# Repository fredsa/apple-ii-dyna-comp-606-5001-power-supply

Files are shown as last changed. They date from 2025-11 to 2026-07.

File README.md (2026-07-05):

# Apple II 605-5703 (DynaComp 606-5001) Power Supply 110v

- KiCad schematic reverse-engineered by Fred Sauer in 2025, 2026.

- Part numbers and compontent layout updated to match power supply schematic
  published in _The Apple II Circuit Description_ (reprint of
  _Apple II Reference Manual 1981_), except for differences indicated by dotted
  outlines marked `diff`.

- Refer to [U.S. Patent 4,130,862](https://patents.google.com/patent/US4130862A)
  for an explanation of key design features of this power supply.

- KiCad and PDF schematic can be found in the `Dyna-Comp-606-5001-KiCad/`
  folder.

<hr>

<table>
  <caption>KiCad schematic</caption>
  <tr>
    <td>
      <a href="Dyna-Comp-606-5001-KiCad.svg">Dyna-Comp-606-5001-KiCad.svg</a><br>
      <a href="Dyna-Comp-606-5001-KiCad.pdf">Dyna-Comp-606-5001-KiCad.pdf</a><br>
    </td>
  </tr>
  <tr>
    <td></td>
  </tr>
</table>

<table>
  <caption>Main circuit board</caption>
  <tr>
    <td>Bottom side (flipped)</td>
    <td>Top side</td>
  </tr>
  <tr>
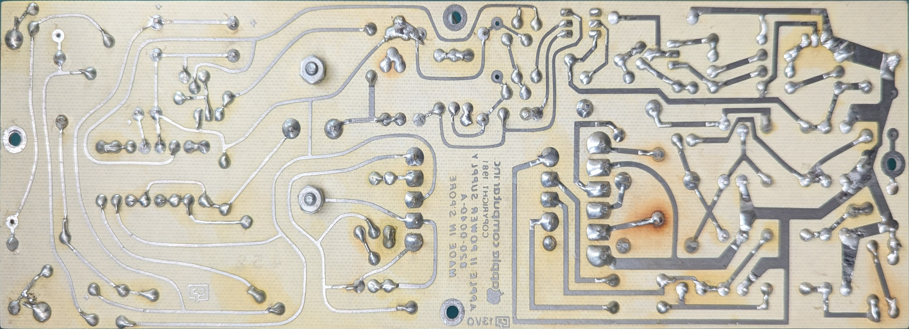
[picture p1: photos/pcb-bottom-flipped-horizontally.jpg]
    <td></td>
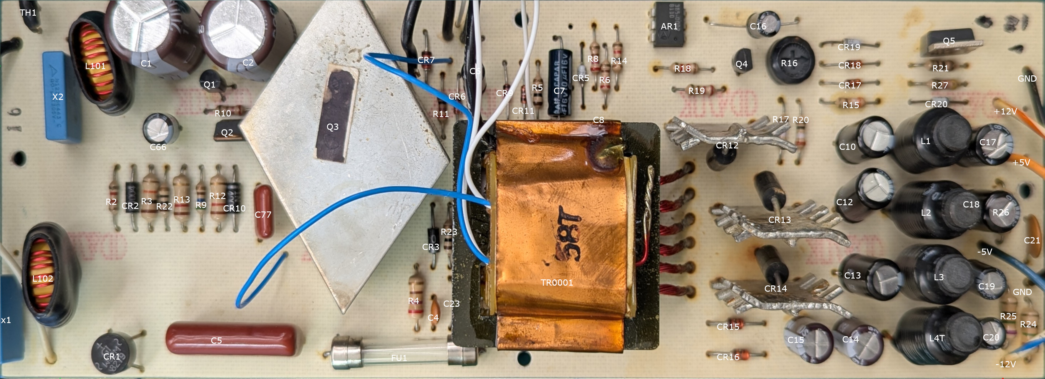
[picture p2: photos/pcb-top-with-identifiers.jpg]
    <td></td>
  </tr>
</table>

<table>
  <caption>Line filter</caption>
  <tr>
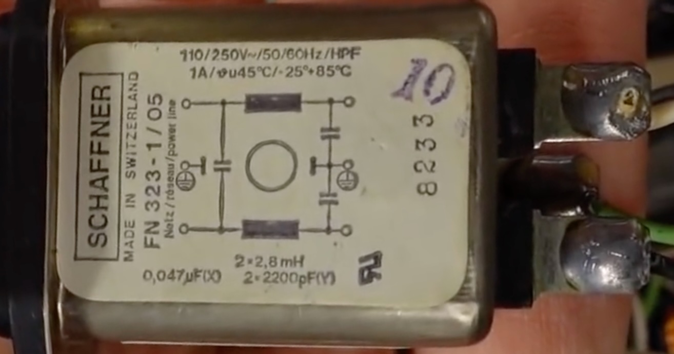
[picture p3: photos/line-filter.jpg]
    <td></td>
  </tr>
</table>

Model number `606-5001`

Specifications: `120 VAC` `60 Hz, 1 AMP`

Made in `DynaComp, Richardson, TX`:

<table>
  <caption>Line filter</caption>
  <tr>
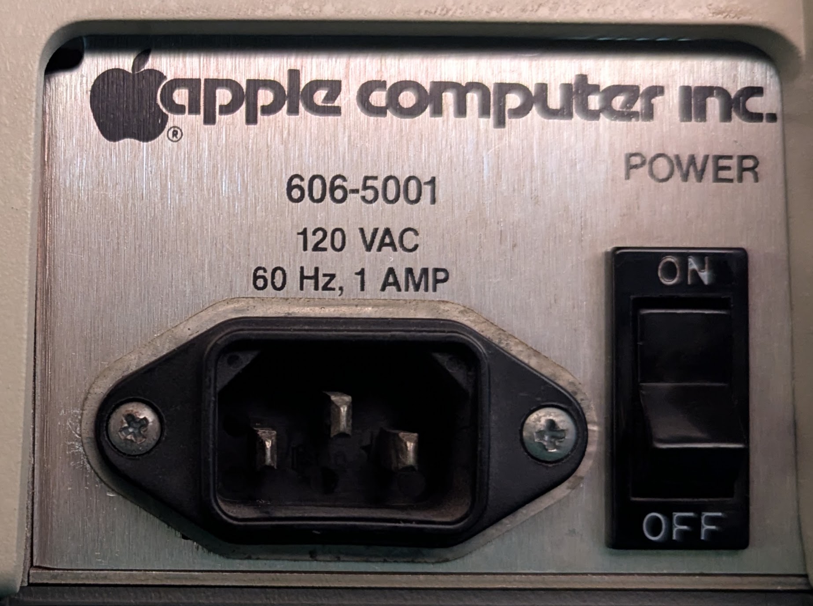
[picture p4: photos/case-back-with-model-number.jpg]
    <td></td>
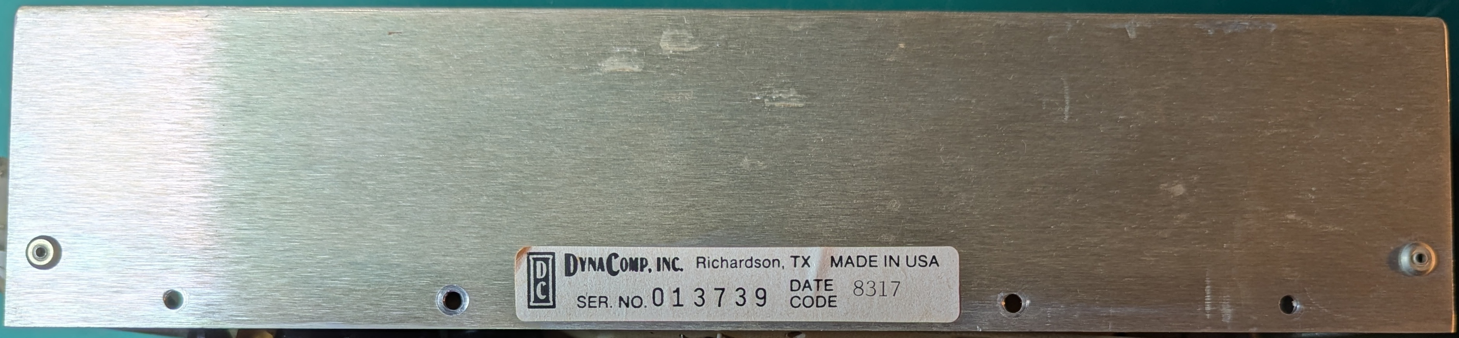
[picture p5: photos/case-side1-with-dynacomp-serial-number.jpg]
    <td></td>
  </tr>
</table>

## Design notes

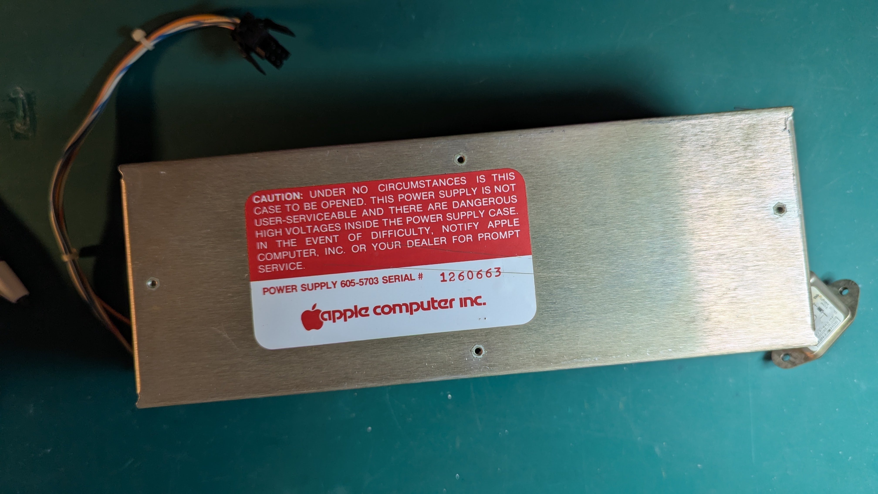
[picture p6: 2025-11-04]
photos/case-side2-with-apple-serial-number.jpg

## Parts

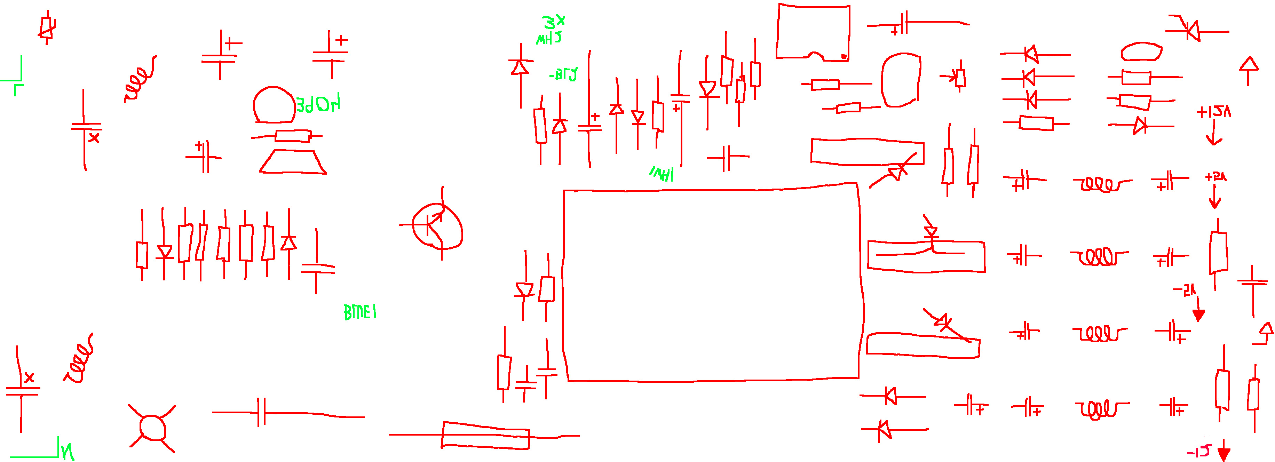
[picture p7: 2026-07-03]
photos/pcb-bottom-components-flipped-horizontally.jpg

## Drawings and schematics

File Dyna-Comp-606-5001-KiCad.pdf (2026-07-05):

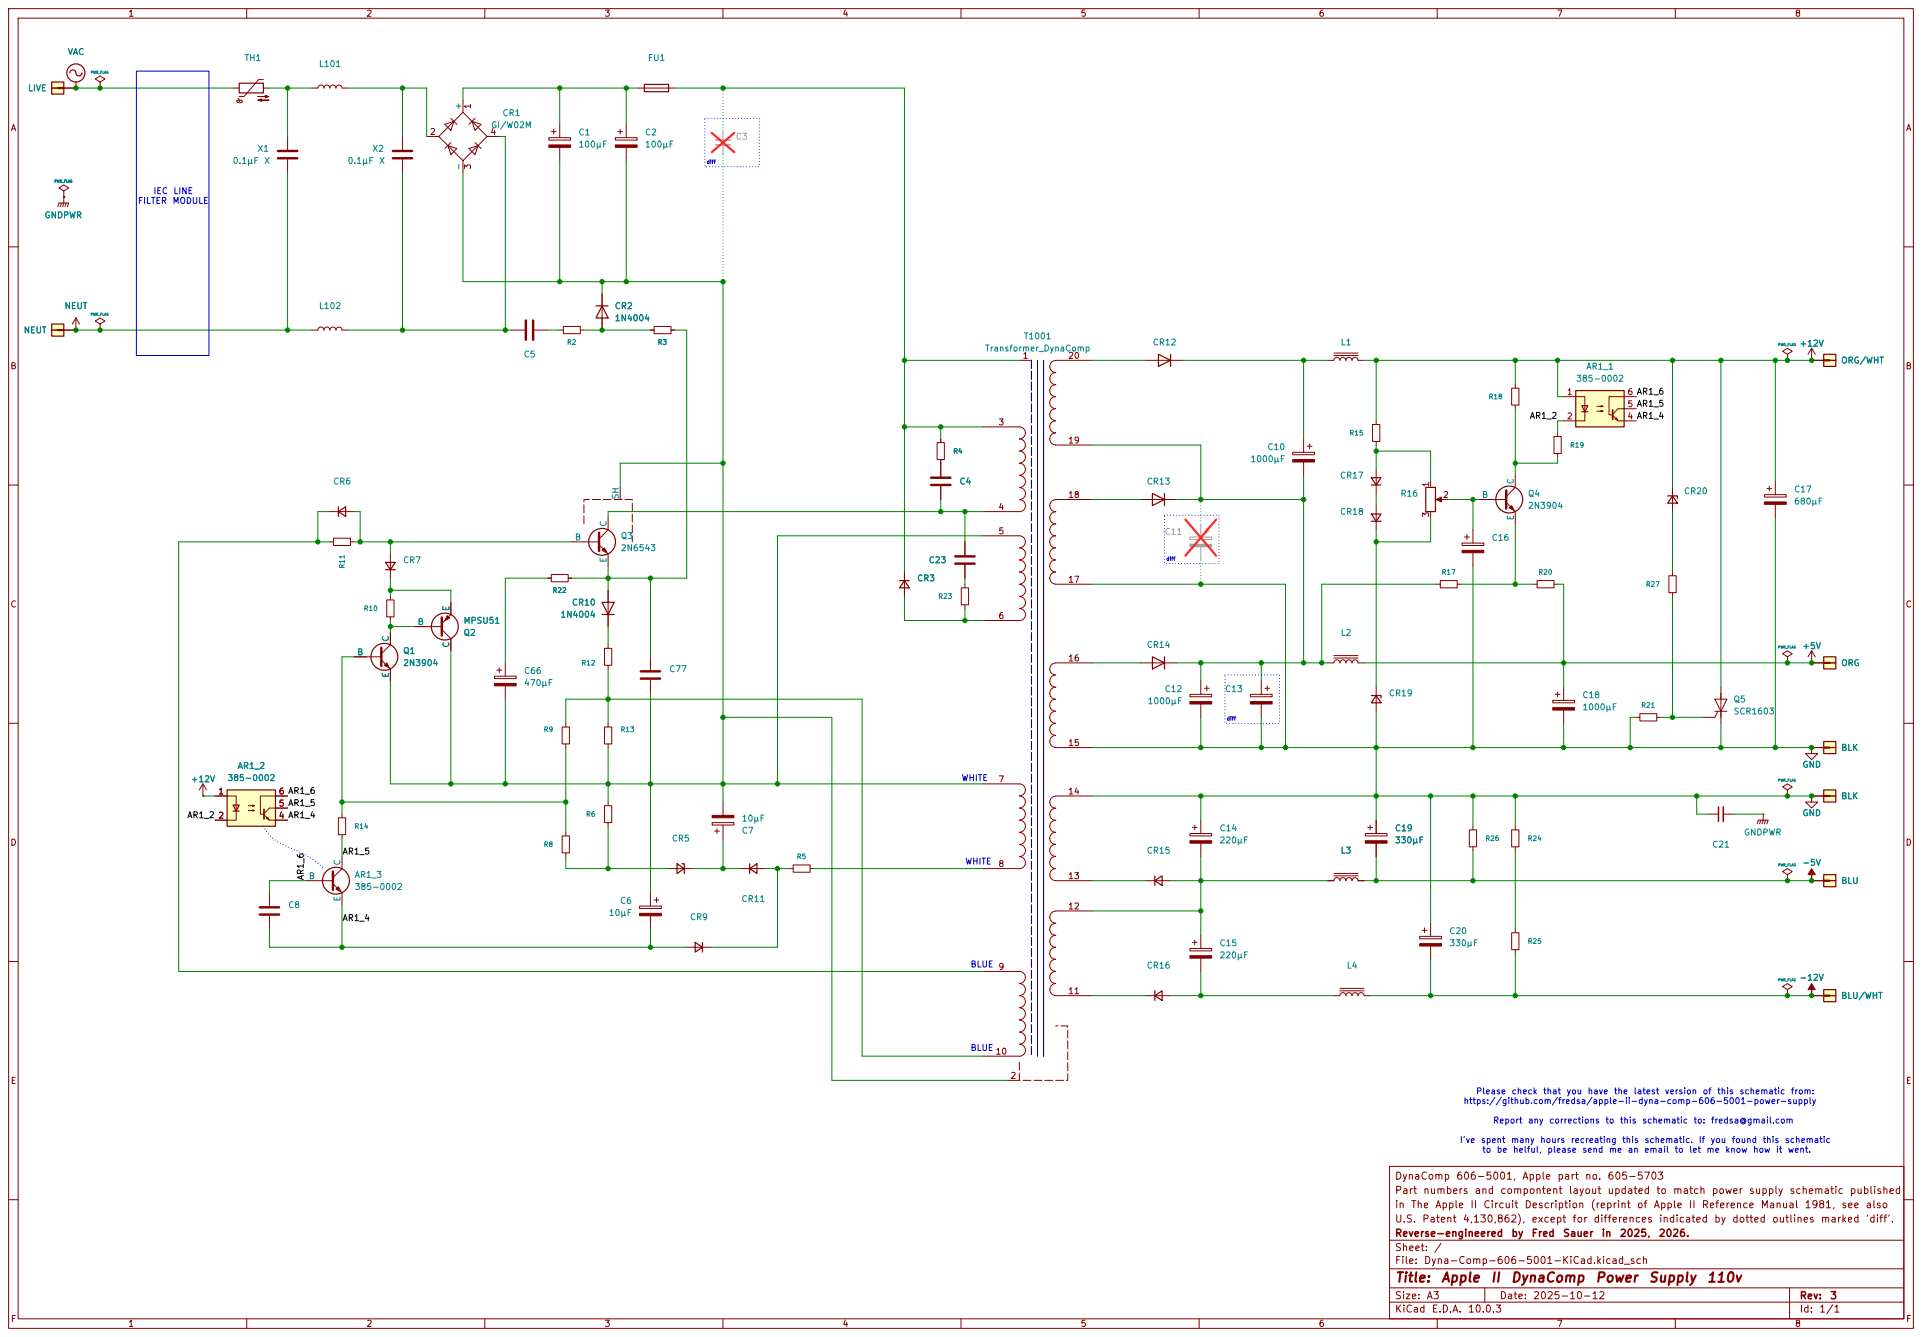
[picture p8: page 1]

AR1_2 WHITE BLUE WHITE BLUE

Please check that you have the latest version of this schematic from: https://github.com/fredsa/apple-ii-dyna-comp-606-5001-power-supply

Report any corrections to this schematic to: fredsa@gmail.com

I've spent many hours recreating this schematic. If you found this schematic
to be helful, please send me an email to let me know how it went.

DynaComp 606-5001, Apple part no. 605-5703
Part numbers and compontent layout updated to match power supply schematic published
in The Apple II Circuit Description (reprint of Apple II Reference Manual 1981, see also
U.S. Patent 4,130,862), except for differences indicated by dotted outlines marked 'diff'.
Reverse-engineered by Fred Sauer in 2025, 2026.
Sheet: /
File: Dyna-Comp-606-5001-KiCad.kicad_sch
Title: Apple II DynaComp Power Supply 110v

Size: A3 | Rev: 3
KiCad E.D.A. 10.0.3 | Id: 1/1 | F Date: 2025-10-12

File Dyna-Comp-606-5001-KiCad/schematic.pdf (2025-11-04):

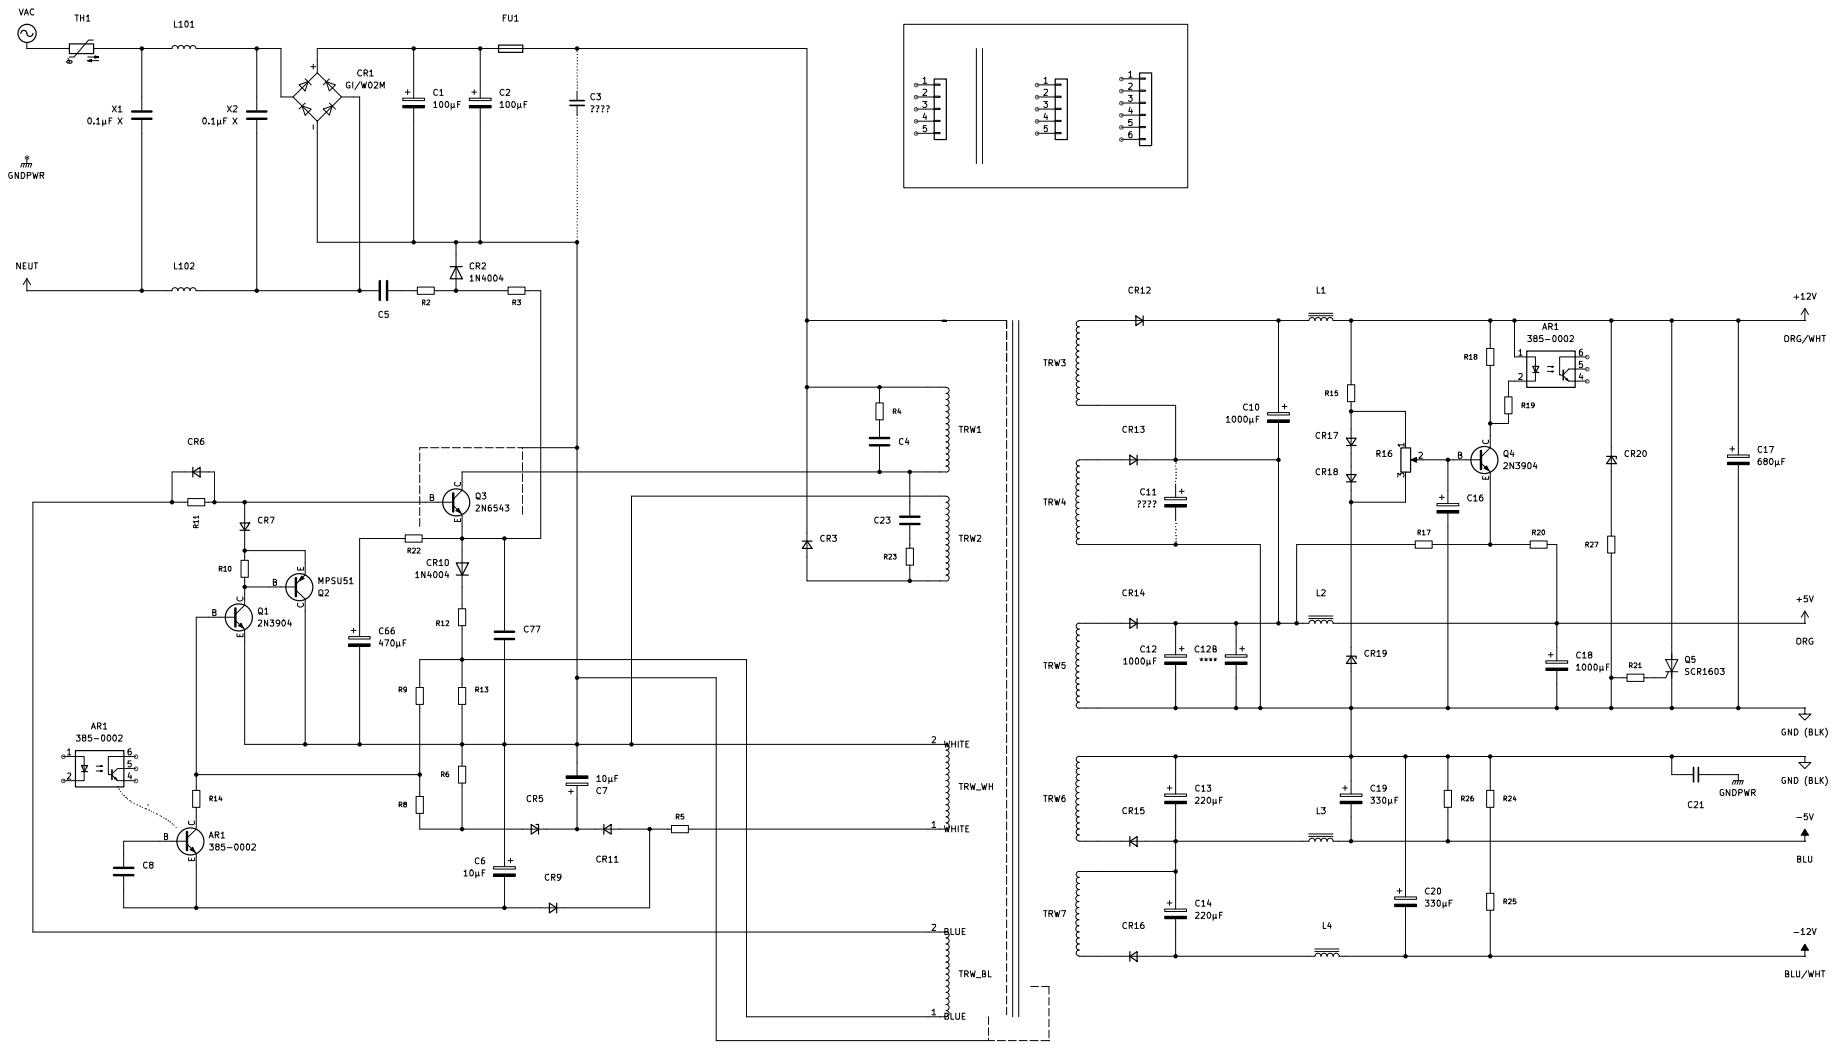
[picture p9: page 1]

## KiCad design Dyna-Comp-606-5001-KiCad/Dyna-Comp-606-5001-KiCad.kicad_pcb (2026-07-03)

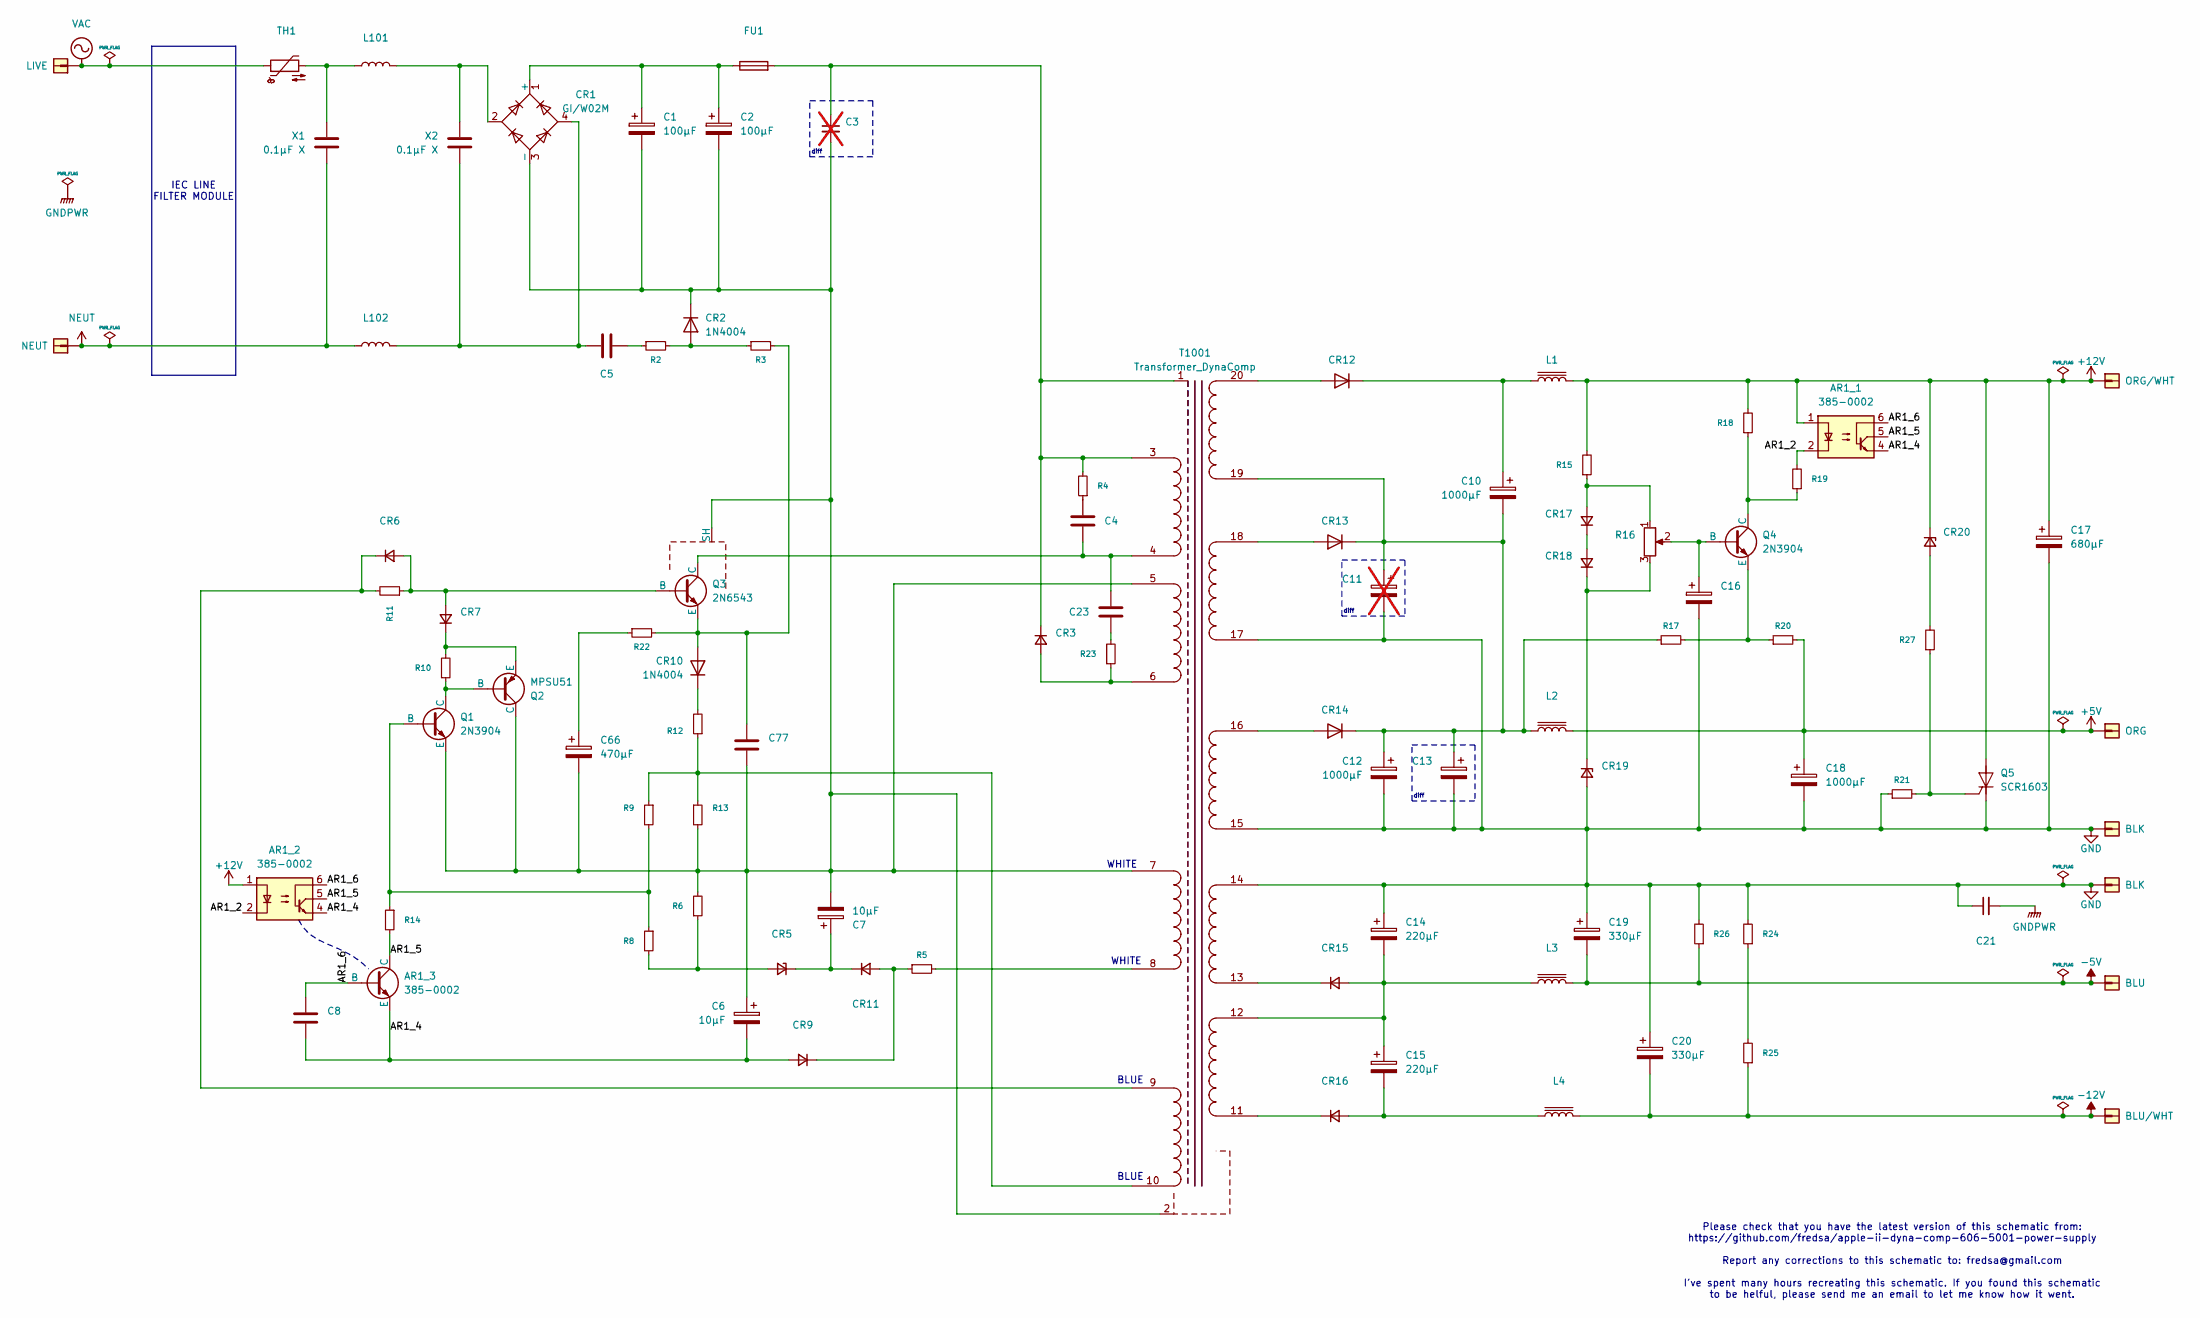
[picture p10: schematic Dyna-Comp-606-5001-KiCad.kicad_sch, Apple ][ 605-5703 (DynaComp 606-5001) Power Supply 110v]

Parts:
AR1_1, AR1_2: 385-0002; DIP-6_W7.62mm
AR1_3: 385-0002
C1, C2: 100µF; CP_Radial_D10.0mm_P7.50mm
C3: C; not fitted
C4: C; C_Disc_D4.3mm_W1.9mm_P5.00mm
C5: C; C_Axial_L17.0mm_D6.5mm_P25.00mm_Horizontal
C6, C7: 10µF; -CP_Axial_P20.5mm_Horizontal
C8: C; C_Disc_D10.0mm_W2.5mm_P5.00mm
C10, C12, C18: 1000µF; CP_Radial_Tantal_D4.5mm_P5.00mm
C11: C; CP_Radial_Tantal_D4.5mm_P5.00mm; not fitted
C13: C; CP_Radial_Tantal_D4.5mm_P5.00mm
C14, C15: 220µF; CP_Radial_Tantal_D4.5mm_P5.00mm
C16: C; CP_Axial_L11.0mm_D5.0mm_P18.00mm_Horizontal
C17: 680µF; CP_Radial_Tantal_D4.5mm_P5.00mm
C19, C20: 330µF; CP_Radial_Tantal_D4.5mm_P5.00mm
C21: C_Small; C_Disc_D10.5mm_W5.0mm_P10.00mm
C23, C77: C; C_Rect_L11.0mm_W2.8mm_P10.00mm_MKT
C66: 470µF; CP_Radial_Tantal_D4.5mm_P5.00mm
CR1: GI/W02M; Diode_Bridge_Round_D9.0mm
CR2, CR10: 1N4004; D_DO-34_SOD68_P12.70mm_Horizontal
CR3, CR6, CR7, CR9, CR11, CR15, CR16, CR17, CR18: D_Small; D_DO-34_SOD68_P12.70mm_Horizontal
CR5, CR20: D_Zener_Small; D_A-405_P12.70mm_Horizontal
CR12, CR13, CR14: D; -D_P10mm_Vertical_CathodeUp-Heatsink
CR19: D_Zener_Small; D_DO-34_SOD68_P10.16mm_Horizontal
FU1: Fuse; Fuse_SunFuse-6HP
J1001, J1002, J1003, J1004, J1005, J1006, J1007, J1008: Conn_01x01; SolderWire-0.25sqmm_1x01_D0.65mm_OD1.7mm
L1, L2, L3, L4: -L_Axial_P9mm
L101, L102: L; -L_Toroid_Vertical_P8.40mm
Q1, Q4: 2N3904; -TO-92_Wide-pin2-fwd
Q2: MPSU51; TO-220F-3_Vertical
Q3: 2N6543; TO-3
Q5: SCR1603; TO-220F-3_Vertical
R2, R3, R4, R5, R6, R8, R9, R10, R11, R12, R13, R14, R15, R17, R18, R20, R21, R22, R23, R24, R25, R26, R27: R_Small; -R_Axial_P12.70mm_Horizontal
R16: R_Potentiometer; Potentiometer_Runtron_RM-063_Horizontal
R19: R_Small; R_Axial_DIN0207_L6.3mm_D2.5mm_P10.16mm_Horizontal
T1001: Transformer_DynaComp; Transformer_EPCOS_B66359J1014T_Vertical
TH1: Thermistor_NTC; R_Axial_DIN0204_L3.6mm_D1.6mm_P5.08mm_Horizontal
X1, X2: 0.1µF X; C_Rect_L16.5mm_W4.9mm_P15.00mm_MKT

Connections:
+5V: C18.1, J1002.1 (ORG_1), L2.2, R20.2
+12V: AR1_1.1, AR1_2.1, C17.1, CR20.1 (K), J1001.1 (ORG/WHT_1), L1.2, Q5.2 (A), R15.2, R18.2
-5V: C19.2, J1005.1 (BLU_1), L3.2, R26.1
-12V: C20.2, J1006.1 (BLU/WHT_1), L4.2, R25.1
/AR1_2: AR1_1.2, AR1_2.2, R19.2
/AR1_4: AR1_1.4, AR1_2.4, AR1_3.1 (E), C6.2, C8.1, CR9.2 (A)
/AR1_5: AR1_1.5, AR1_2.5, AR1_3.3 (C), R14.2
/AR1_6: AR1_1.6, AR1_2.6, AR1_3.2 (B), C8.2
GND: C11.2, C12.2, C13.2, C14.1, C16.2, C17.2, C18.2, C19.1, C20.1, C21.1, CR19.2 (A), J1003.1 (BLK_1), J1004.1 (BLK_1), Q5.3 (K), R21.1, R24.2, R26.2, T1001.14 (SD), T1001.15 (SE), T1001.17 (SG)
GNDPWR: C21.2
NEUT: J1007.1 (NEUT_1), L102.1, X1.2
unnamed: C4.1, R4.1
unnamed: C5.1, R2.1
unnamed: C5.2, CR1.4, L102.2, X2.2
unnamed: C23.2, R23.2
unnamed: C66.1, R22.1
unnamed: C1.1, C2.1, CR1.1 (+), FU1.1
unnamed: C1.2, C2.2, C3.2, C6.1, C7.2, C66.2, C77.1, CR1.3 (-), CR2.1 (K), Q1.1 (E), Q2.1 (C), Q3.0 (SH), R6.2, R13.2, T1001.2 (SH), T1001.5 (AC), T1001.7 (AE)
unnamed: CR1.2, L101.2, X2.1
unnamed: CR2.2 (A), R2.2, R3.1
unnamed: CR3.2 (A), R23.1, T1001.6 (AD)
unnamed: C3.1, CR3.1 (K), FU1.2, R4.2, T1001.1 (CORE), T1001.3 (AA)
unnamed: CR5.2 (A), R6.1, R8.2
unnamed: CR6.2 (A), CR7.2 (A), Q3.1 (B), R11.1
unnamed: CR6.1 (K), R11.2, T1001.9 (AG)
unnamed: CR7.1 (K), Q2.3 (E), R10.2
unnamed: C77.2, CR10.2 (A), Q3.2 (E), R3.2, R22.2
unnamed: CR10.1 (K), R12.2
unnamed: CR9.1 (K), CR11.2 (A), R5.1
unnamed: C7.1, CR5.1 (K), CR11.1 (K)
unnamed: CR12.2 (A), T1001.20 (SJ)
unnamed: C10.1, CR12.1 (K), L1.1
unnamed: CR13.2 (A), T1001.18 (SH)
unnamed: C10.2, C11.1, C12.1, C13.1, CR13.1 (K), CR14.1 (K), L2.1, R17.1, T1001.19 (SI)
unnamed: CR14.2 (A), T1001.16 (SF)
unnamed: C14.2, C15.1, CR15.2 (A), L3.1, T1001.12 (SB)
unnamed: CR15.1 (K), T1001.13 (SC)
unnamed: C15.2, CR16.2 (A), L4.1
unnamed: CR16.1 (K), T1001.11 (SA)
unnamed: CR17.2 (A), R15.1, R16.1
unnamed: CR17.1 (K), CR18.2 (A)
unnamed: CR18.1 (K), CR19.1 (K), R16.3
unnamed: CR20.2 (A), R27.2
unnamed: L101.1, TH1.2, X1.1
unnamed: Q1.2 (B), R8.1, R9.2, R14.1
unnamed: Q1.3 (C), Q2.2 (B), R10.1
unnamed: C4.2, C23.1, Q3.3 (C), T1001.4 (AB)
unnamed: C16.1, Q4.2 (B), R16.2
unnamed: Q4.3 (C), R18.1, R19.1
unnamed: Q4.1 (E), R17.2, R20.1
unnamed: Q5.1 (G), R21.2, R27.1
unnamed: R24.1, R25.2
unnamed: R5.2, T1001.8 (AF)
unnamed: R9.1, R12.1, R13.1, T1001.10 (AH)
VAC: J1008.1 (LIVE_1), TH1.1

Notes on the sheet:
WHITE
IEC LINE FILTER MODULE
BLUE
diff
Please check that you have the latest version of this schematic from: https://github.com/fredsa/apple-ii-dyna-comp-606-5001-power-supply Report any corrections to this schematic to: fredsa@gmail.com I've spent many hours recreating this schematic. If you found this schematic to be helful, please se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

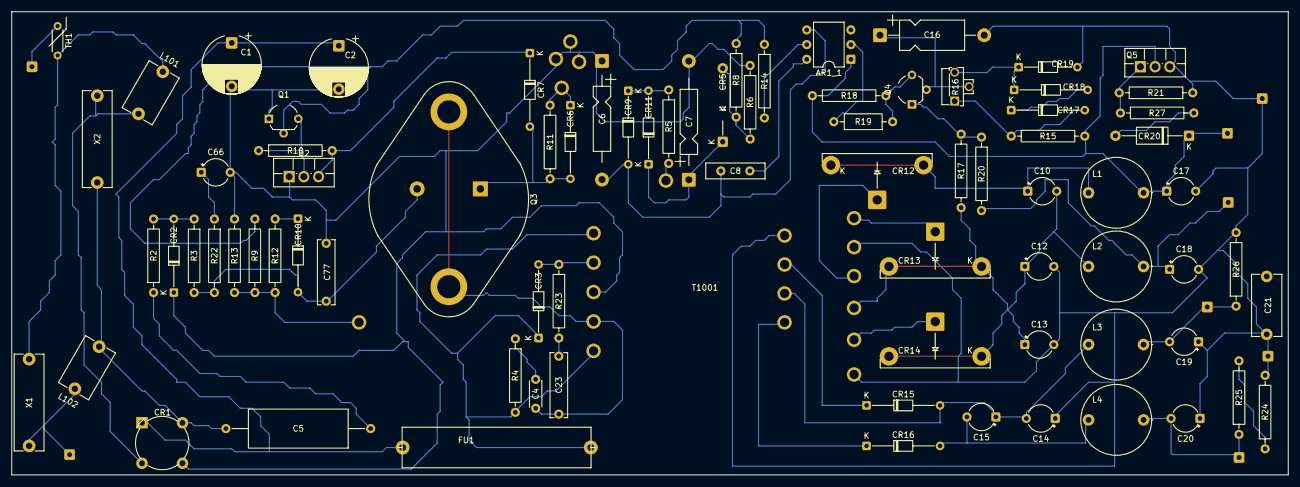
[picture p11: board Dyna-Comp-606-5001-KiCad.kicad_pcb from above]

Board: 2 copper layers, 220.5 x 80.0 mm, 89 parts (0 on the bottom side), 54 nets.

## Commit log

2025-11-04 Reverse-engineered KiCad files
    [Dyna-Comp-606-5001-KiCad.kicad_pcb, Dyna-Comp-606-5001-KiCad.kicad_sch]
2025-11-04 Updated schematic title to include Apple part number
    [Dyna-Comp-606-5001-KiCad.kicad_sch]
2026-07-03 V2, corrections, IEC filter, PCB layout
    [Dyna-Comp-606-5001-KiCad.kicad_pcb, Dyna-Comp-606-5001-KiCad.kicad_sch]
2026-07-05 Updated descriptions, publish PDF, SVG
    [Dyna-Comp-606-5001-KiCad.kicad_sch]
